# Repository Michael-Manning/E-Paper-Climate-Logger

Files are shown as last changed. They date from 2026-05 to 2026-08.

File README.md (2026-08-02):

# Weathergotchi - an E-Paper Climate Logger

## About

This project is an open-source, battery-powered temperature and humidity data logger with an always-on e-paper display. It records ambient conditions over time, stores readings in non-volatile memory, and displays current data along with a history graph. The device is designed for low power consumption, over 2 weeks of operation on a small Li‑Po battery.

Key features:

- ESP32-S3 with deep sleep & RTC timer to wake up
- Temperature and humidity sensor with external EEPROM for logging
- Accurate battery monitoring and charging management
- Power button controller to turn on/off
- 1.54‑inch e‑paper display
- Custom PCB & 3D‑printed case
- Over 2 weeks of battery life on a single charge

The entire project is open source, including hardware schematics, PCB layout, firmware, and enclosure CAD files. A detailed build video is available on YouTube: [E-Paper Climate Logger](https://www.youtube.com/watch?v=I44iGj7gLGA).

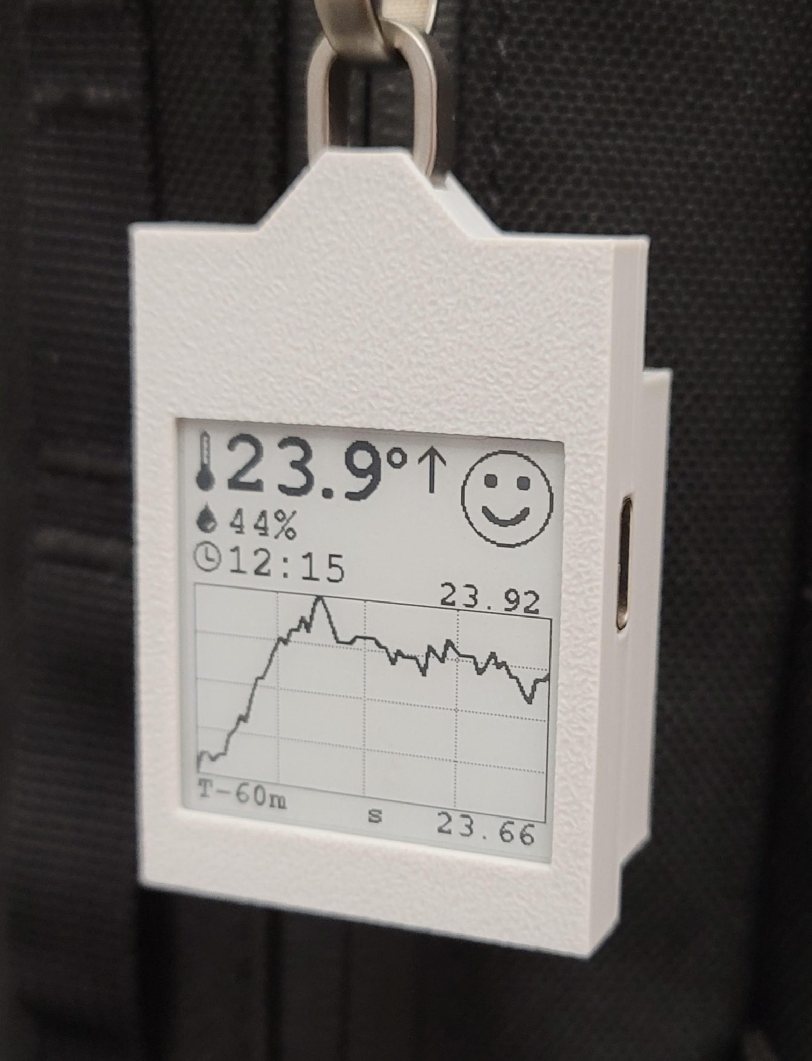
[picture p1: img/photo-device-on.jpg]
photo-device-on

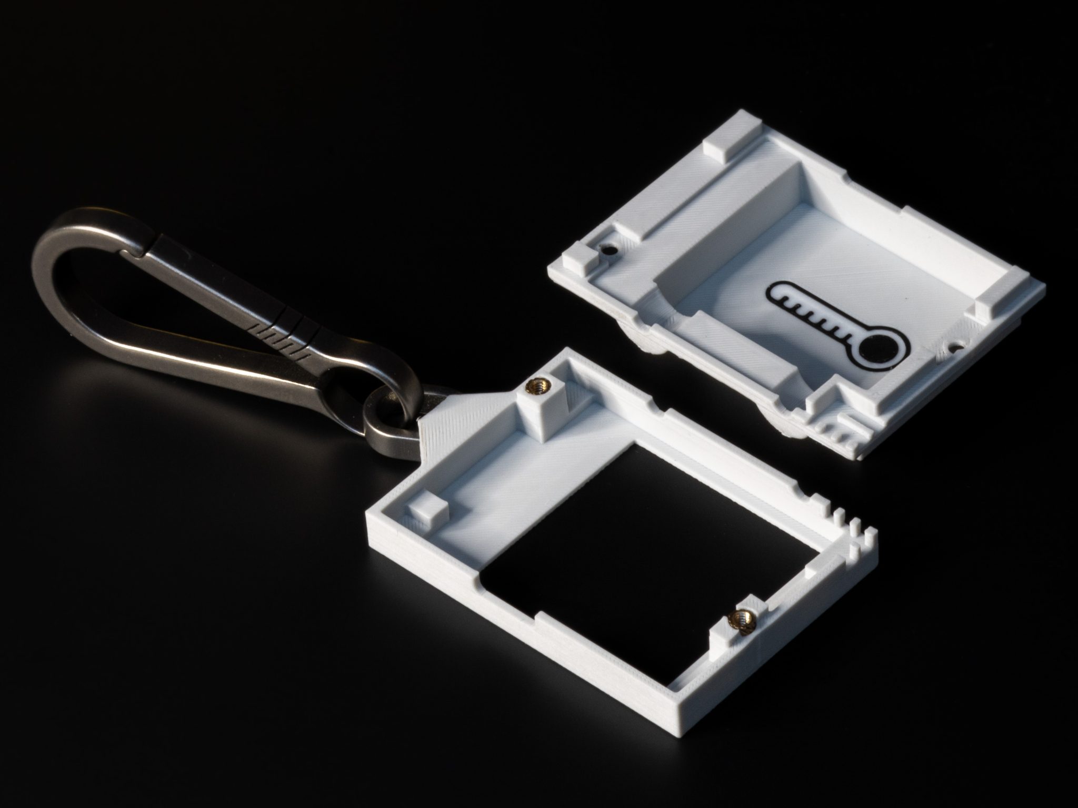
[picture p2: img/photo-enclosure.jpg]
photo-enclosure

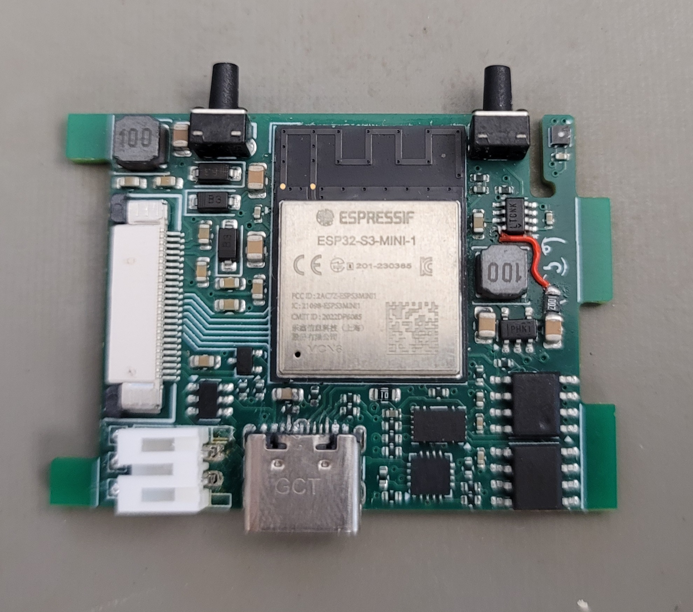
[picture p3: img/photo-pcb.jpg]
photo-pcb


### Youtube video

E-Paper Climate Logger (https://youtu.be/I44iGj7gLGA)

## Repository Structure

```
E-Paper-Climate-Logger/
├── CAD/                 # 3D case design (OpenSCAD source and STL exports)
├── PCB/                 # KiCad hardware design, schematics, datasheets, references
├── firmware/            # PlatformIO firmware (ESP32-S3, Arduino framework)
├── LICENSE              # License file
└── README.md            # This file
```

### CAD

Contains the parametric OpenSCAD models for the front and back case halves, assembly files, and exported STLs for 3D printing. The design is fully parametric – dimensions can be adjusted by editing `constants.scad`.

### PCB

All hardware design files for the custom mainboard (`templog_mainboard`). This directory includes:

- KiCad project files (`.kicad_sch`, `.kicad_pcb`, `.kicad_pro`)
- Schematic sheets for power management and display driver
- Component footprints and 3D models
- Datasheets for all major ICs (charger, fuel gauge, RTC, sensors, etc.)
- Reference schematics from SparkFun and Waveshare

To view or modify the PCB design, install KiCad 9 or later and open `templog_mainboard.kicad_pro`.

### Firmware

PlatformIO project for the ESP32‑S3 using the Arduino framework. It handles sensor reading, timekeeping, data logging to EEPROM, e‑paper display updates, button handling, and power management (deep sleep, wake sources). See `firmware/README.md` for detailed build and flashing instructions.

## Getting Started

### Hardware Prerequisites

- Assembled E-Paper Climate Logger PCB (or a hand‑soldered prototype – note that many components are small and may require reflow soldering)
- 1.54‑inch e‑paper display (compatible with Waveshare pinout)
- 3D‑printed case (files in `CAD/export/`)
- Li‑Po battery (e.g., 400 mAh, single cell)
- USB‑C cable for charging and programming

### Building the Firmware

1. Install [PlatformIO Core](https://platformio.org/install/cli) (or use the PlatformIO extension in VS Code).
2. Navigate to the `firmware` directory.
3. Connect the device via USB‑C.
4. Run:

   ```
   pio run --target upload
   ```

5. Monitor serial output (optional):

   ```
   pio device monitor
   ```

For detailed firmware documentation, including folder structure, driver details, and low‑power operation, refer to [`firmware/README.md`](firmware/README.md).

### Enclosure Assembly

Print the STL files from `CAD/V2/export/` using a high‑resolution FDM printer (0.08 mm layer height recommended). The case uses M2 heat set inserts and M2 screws. Insert the PCB and battery, then screw the front and back halves together. See note.txt in CAD\V2 for more details.

## Hardware Overview

All I2C peripherals (SHT45, DS3231, 24LC512, BQ27441) share the same bus. The e‑paper display is driven via SPI, and the LTC2954 soft power button controls system power-off via the BQ24075.

For complete schematics and PCB layout, open the KiCad project in `PCB/templog_mainboard/`.

## Power Management and Low‑Power Operation

The device is designed to run for over 2 weeks on a small battery:

- In deep sleep, the ESP32‑S3 draws less than 20 µA. The DS3231 and BQ27441 remain active with negligible current.
- The DS3231 alarm wakes the ESP32 at a configurable interval (default: 1 minute). The ESP32 wakes, logs a reading (about 400 ms at 50 mA), updates the display, and returns to sleep.
- The LTC2954 provides a true on/off capability.

## Issues
- **Battery accuracy issues**: In my testing, the reported battery state of charge is not accurate. I believe this is due to a misconfiguration BQ27441.
- **Low battery issues**: In my testing, when connecting a battery to the device, it will sometimes not turn on until the battery has been connected/disconnected multiple times. 

## Notes on building your own device

I don't have a detailed build guide on how to build your own device at this time, but if you do decide to make one, these are some details you should know.

- First firmware upload requires putting the ESP32-S3 in boot mode. There are three pads near the battery input that expose, BOOT, Enable, and ground. Attaching leads to these pins will allow you to put the ESP32 in boot mode.
- The back of the PCB must be completely flat in order to fit in the case with the screen. After soldering through-hole components. like the buttons, you may need a dremel to flatten the leads/solder on the back of the PCB.

## Troubleshooting

- **Device does not power/stay on:** Ensure the battery is charged to at least 3.7V and try disconnecting/reconnecting the battery. Sometimes the battery must be reconnected multiple times before booting for the first time.
- **Battery percentage inaccurate:** The BQ27441 requires a one-time capacity configuration; refer to the datasheet and adjust `BQ27441.cpp`. The fuel gauge also needs to "learn" the battery before it reports an accurate  state of charge. Fully charge the battery, then wait for it to completely deplete. This will help the fuel gauge report a more accurate charge level.
- **Cannot upload program to the device:** Before uploading for the first time, the device must be manually put in boot mode. See the above note in building your own device.

## Limitations
- **Temperature accuracy during handling**: The ESP32 generates heat when active, which can affect the SHT45 reading. The firmware reads the sensor immediately upon wake to minimize this error. Prolonged menu browsing or holding the device will skew the ambient reading for several minutes.
- **Display low‑temperature limit**: The e‑paper module is rated for operation above 0°C. Below freezing, the screen may not update reliably. Data logging continues in the background, and display functionality resumes when the temperature rises.
- **No wireless connectivity**: While this device has the physical capability for bluetooth and WIFI, The current version of the firmware does not support it or allow you to use the radio to export data. Data can be viewed only on the device screen.

## Contributing

Issues, pull requests, and suggestions are welcome. Please follow the existing code style and document any changes to the hardware or firmware.

## License

Refer to the `LICENSE` file in the root directory for licensing terms (open source, permissive).

## Acknowledgements

- SparkFun for the Battery Babysitter reference design
- Waveshare for e‑paper display modules and driver schematics
- The PlatformIO and GxEPD2 communities

For questions or discussions, open an issue on GitHub or visit the YouTube video comments.

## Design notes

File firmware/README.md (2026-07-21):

# Weathergotchi - an E-Paper Climate Logger firmware

## Overview

The firmware runs on an ESP32-S3 microcontroller and is built using PlatformIO with the Arduino framework. It reads temperature and humidity from an SHT45 sensor, stores records in a 24LC512 EEPROM, monitors battery status via a BQ27441 fuel gauge, and displays information on an e-paper screen. The system is designed for low-power operation, entering deep sleep between measurement intervals and waking via the RTC alarm or user buttons.

## Getting Started

### Prerequisites

- PlatformIO Core (installed via pip or standalone installer)
- USB-C cable for programming and power
- Assembled E-Paper Climate Logger hardware

### Dependencies

All required libraries are specified in `platformio.ini` and will be fetched automatically by PlatformIO. The main dependencies include:

- GxEPD2 (e-paper display driver)

The Arduino framework and ESP32-S3 board definition are also handled automatically.

### Building and Flashing

1. Clone the repository and navigate to the firmware directory.
2. Connect the device via USB-C.
3. Build and upload:

   ```
   pio run --target upload
   ```

4. Monitor serial output (optional):

   ```
   pio device monitor
   ```

## Folder Structure

```
firmware/
├── src/
│   ├── drivers/               # Low-level hardware drivers
│   │   ├── BQ27441.cpp/h      # Battery fuel gauge
│   │   ├── BQ27441_Definitions.h
│   │   ├── DS3231.cpp/h       # Real-time clock
│   │   ├── EEPROM.cpp/h       # 24LC512 external EEPROM
│   │   ├── SHT45.cpp/h        # Temperature/humidity sensor
│   │   └── display.cpp/h      # E-paper display (GxEPD2 wrapper)
│   ├── Constants.h            # System-wide constants (sleep intervals, etc.)
│   ├── MAssert.h              # Debug assertions
│   ├── app.cpp/h              # Application state machine and main logic
│   ├── bitmaps.h              # Image data for the display
│   ├── buttons.cpp/h          # Debounced button handling
│   ├── debugLog.h             # Logging macros
│   ├── main.cpp               # Entry point, setup() and loop()
│   ├── pinout.h               # GPIO pin mapping
│   ├── platform.cpp/h         # Hardware abstraction (initialization)
│   ├── power.cpp/h            # Sleep management and wake sources
│   └── timer_setter.h         # Alarm configuration for DS3231
├── extra_script.py            # PlatformIO pre-build script
├── platformio.ini             # Build configuration
└── README.md
```

## General Operation

The firmware executes a simple state machine:

1. **Wake Up Routine**  
   - Climate reading is immediately taken from the SHT45.
   - EEPROM is read to dermine the state of the device.
   - If the device was woken up from the DS3231 alarm:
        - The climate reading is stored to EEPROM.
        - The e-paper display is refreshed with the latest data.
        - The device then returns to deep sleep.

2. **Main Application**  
   - If wake up source was one of the buttons (user interactivity), the device enters the application loop.
   - Different screens and menus can be accessed using the buttons.
   - New settings may be written to EEPROM.
   - Device returns to deep sleep after 10 seconds of innactivity.

3. **Button Handling**  
   - **Power button (GPIO14)** - Wakes device from sleep and opens the main menu.
   - **Menu button (GPIO2)** - Used for navigating the GUI: Debug menu, Settings, Set time
   - **Hold power button 3+ seconds** - Graceful shutdown (LTC2954 cuts power after 6 seconds)

## Operational Notes

### Low-Power Design

- The ESP32-S3 enters deep sleep between logging intervals (default: every 1 minute). 
- Deep sleep current is minimised by disabling unused peripherals.  
- The DS3231 generates a periodic alarm on its INT pin (GPIO21) to wake the MCU.  
- Button wake is enabled via GPIO interrupts.  
- The display is updated only when new data is available or upon user request; no continuous screen refresh occurs.
- The device consumes the majority of its energy during the brief wake period (approximately 3 seconds at 50 mA). Deep sleep current is less than 20 µA (ESP32-S3 + DS3231 + BQ27441). Therefore, reducing the wake interval (e.g., to 5 minutes) will proportionally extend battery life, while a shorter interval (e.g., 30 seconds) will reduce it.
- The DS3231 RTC is configured to generate an alarm **every minute** at second 0. This is hardcoded in `DS3231::SetAlarm1(0)` and cannot be changed without code modification.

### Sleep Behavior

The device implements two sleep levels:
1. **Light sleep** - After 1 second of inactivity. Wakes from buttons, alarm, or 9-second timer.
2. **Deep sleep** - After 10 seconds of inactivity. Wakes only from power button or RTC alarm.

### Logging and Storage

- Data records are stored as binary structs in the 24LC512 EEPROM.  
- The storage implements a circular buffer: when the EEPROM is full, the oldest record is overwritten.  
- A small header area stores the current write index and total record count.  
- Records up to 8 hours ago can be displayed on the e-paper screen on the history menu.
- Upon next power‑on, the firmware reads a flag to determine whether it is resuming from deep sleep or from a complete power‑off. This allows proper initialisation of the real‑time clock, display, and user interface state.

### Temperature Sensor Accuracy

The ESP32‑S3 generates heat during wake‑up and active operation. This heat can conduct through the PCB and affect the SHT45 reading, artificially raising the measured temperature. To mitigate this error, the firmware:

- Reads the sensor immediately upon waking, before any other processing.
- Completes the measurement within the first few milliseconds of wake‑up.

For the most accurate ambient logging, avoid handling the device or placing it in direct sunlight while it is awake.

### Display Low‑Temperature Limit

The e‑paper display module is rated for operation only above 0°C. When the ambient temperature falls below freezing:

- The device continues to log temperature and humidity to EEPROM.
- The screen displays a low temperature warning and stops updating.
- Once the temperature rises above 0°C, normal display operation resumes.
- This is a hardware limitation of the display, not a firmware bug.

### Power Management Hardware

The system includes an LTC2954 soft power button controller and a BQ24075 power path IC. The LTC2954:

- Runs directly from the battery with < 1 µA quiescent current.
- Monitors the physical power button (connected to its `PB_IN`).
- Toggles the enable line of the BQ24075 to completely disconnect or restore battery power.
- Provides a button state output (GPIO14) to the ESP32.
- Accepts a `KILL` input (GPIO37) from the ESP32 to trigger a software shutdown.

## Building Custom Hardware

If you are building a variant of the hardware, update `pinout.h` to match your GPIO assignments. The power management logic (charge status, USB detect, power kill) can be adjusted in `power.cpp` and `platform.cpp`.

---

This README focuses on the firmware as it exists in the repository, using PlatformIO and Arduino. For hardware schematics and PCB design, refer to the `PCB` folder at the root of the project.

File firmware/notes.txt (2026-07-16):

TODO:
- add button sequence to factory reset the EEPROM and fuel gauge
- should re-render display when time range setting is changed, or if new climate data has arrived while the user was in the menu.
- replace datetime version that only has hour/minute/second. Change read/write to only use those registers to save time
- can do some async i2c stuff, like when hibernating, you can hibernate the display at the same time as the eeprom is updated
- create mock EEPROM driver and create unit tests to verify data retrieval logic and ensure there are not bugs related to ring buffer edges.
- update firmware update script to send over the current time before uploading the firmware. That way you get a free clock synchronization every time you upload.
- activate fuel gauge hibernation mode when powering off

Bugs:
- on rare occasion, the display will do a full refresh as the main menu is entered. It should only ever do partial refreshes.
- when the battery first dips below the dead threshold voltage, it can possibly bounce back above the threshold depending on power draw and temperature. This means you can potentially turn it back on few a minutes after the battery dies
    - create some sort of latch in the eerpom so that once the battery dies the device stays in it's dead state until it's actually been connected to a charger for a few minute at least.
- when staying in menus for over a minute, climate samples are stored, but the graph does not show the recent samples until the next natural wake up cycle. Fix: update global sample buffer in addition to calling AddClimateSample()
- connecting the charging cable, then it sometimes causes the device to get stuck on the charging screen until a button is pressed.

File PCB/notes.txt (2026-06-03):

------------- Parts -------------

sensor:
SHT45

controller:
ESP32-S3-MINI-1

eeprom:
24LC512

fuel guage:
BQ27441

charger:
BQ24075

battery:

RTC:
DS3231MZ

USB connector:
GCT USB4105

Power path selector:
LM66200DRLR

USB voltage regulator:
TLV75533PDBVR

connector
FPC-05F-24PH20

------------- I2C Addresses -------------
7 bit representation / 8 bit representation

DS3231MZ:
0x68 / 0xD0

SHT45-A (letter determines address)
0x44

BQ27441
0x55

24LC512 (last three bits are determined by A0, A1, A3 pins. Set all to ground for 000)
0x50

------------ References --------------

Battery management reference:
https://cdn.sparkfun.com/assets/learn_tutorials/5/3/0/sparkfun-battery-babysitter-v10-schematic.pdf

esp32 raw e-ink driver example PCB:
https://www.waveshare.com/wiki/E-Paper_ESP32_Driver_Board

pinouts:
https://github.com/atomic14/esp32-s3-pinouts

https://www.waveshare.com/wiki/1.54inch_e-Paper_Module_Manual#Resources

------------ Problems ----------------

Charging rate is very slow. The BQ2407 resister configuration is set to the slowest charging rate which takes over an hour.

fuel gauge GPOUT has a battery level pullup. This required a trace cut because it should be pulled up to 3.3V. Add back in with a voltage divider.

CHG status is not connected to an RTC pin, so the device can't be automatically woken up by USB connection.
USBdetect pin cannot be used instead because it does not pull low.

board capacitance takes over 10 seconds to bring 3.3v rail to 0v. This causes the display to artifact when powering down. 
Might need a mosfet to completely power down the display, or some way to discharge the leftover power

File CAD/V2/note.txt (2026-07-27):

I wanted the case to have rounded corners, so I made this version in FreeCAD.

The model works well, but the parameters are a mess. I just copied over all the variables from the OpenSCAD model and didn't even use half of them.

The other big change is that this version uses 5mm M2 screws without a heat insert. It just has self tap holes to make assembly easier.
It also has a small retention clip on the corner furthest from a screw to help keep it flat.

Notes for putting it together with this case:
- don't use/desolder the battery connector. This case only fits if you solder the battery directly to the PCB.
- Tuck the excess battery wire into the side of the battery compartment.
- Print with a 0.2mm nozzle and 0.08mm layer height.
- Print in PLA and use PETG for the support interface layer on the back for smoother finish.
- Sand the edges and corners of the PCB if the fit is too tight.
- Do not force anything. It should come together easily and the case will bend if you force it together.
- The case is designed to be connected to an titanium clip commonly found on Aliexpress (see clip.png). When slicing the front of the case, insert a pause on the last layer before the clip insertion slot is closed up. Remove the small loop of the clip and place it into the slot before resuming the print so that it stays captive inside the case. I  reccomend adding a 0.8mm tall platform near the top of the case as well so that the loop lays perfectly flat when being printed over.

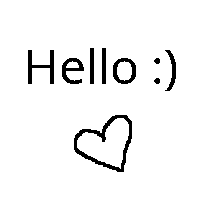
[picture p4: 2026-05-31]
firmware/bitmapGenerator/images/welcom_screen.bmp

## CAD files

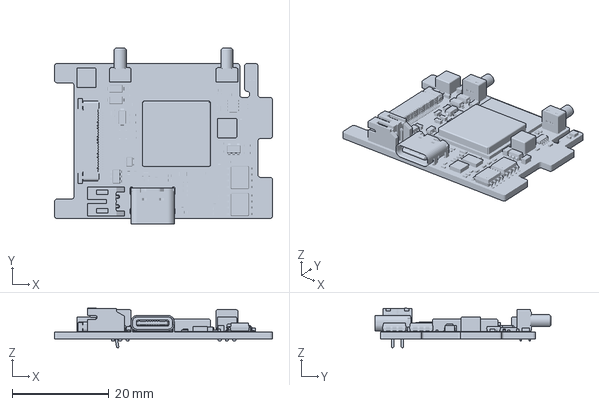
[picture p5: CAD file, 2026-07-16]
CAD/V2/mainboard.FCStd
45.0 x 36.3 x 8.25 mm

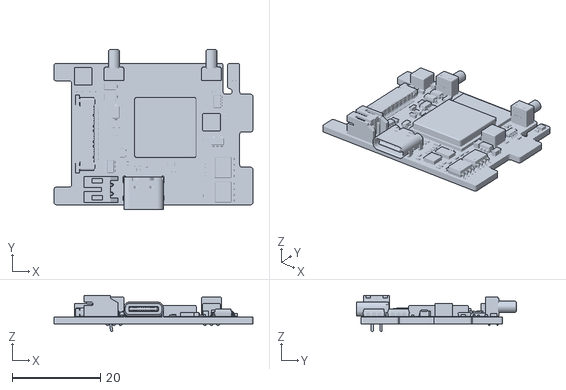
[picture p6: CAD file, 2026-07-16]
CAD/V2/templog_mainboard.stl
45.0 x 36.3 x 8.25

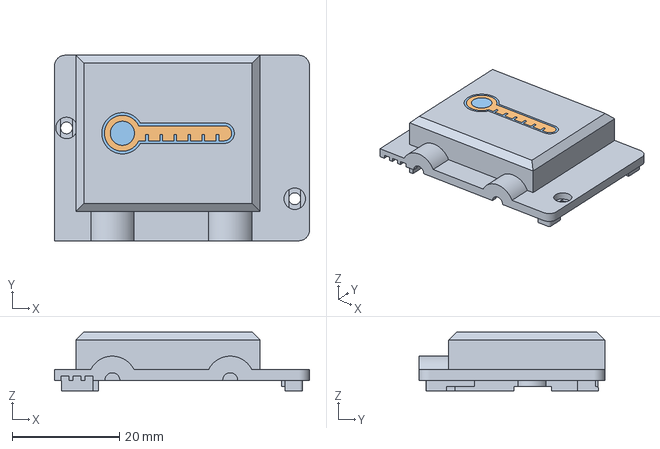
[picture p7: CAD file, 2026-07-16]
CAD/V2/export/case_back_multi_color.3mf
47.6 x 34.6 x 11.0 mm

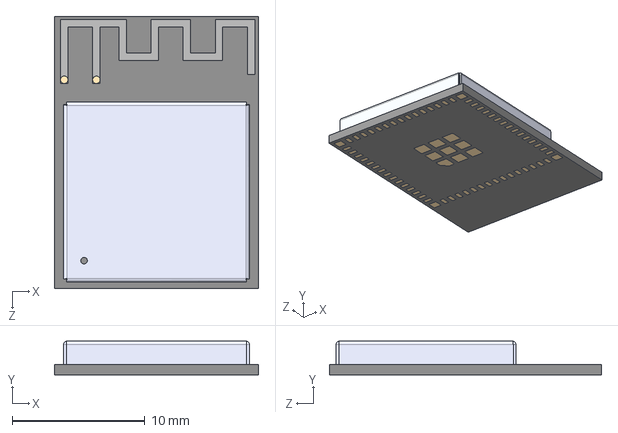
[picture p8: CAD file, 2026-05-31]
PCB/templog_mainboard/PartLibrary/ESP32_S3_MINI_1/3DModel/ESP32-S3-MINI-1.STEP
15.4 x 2.55 x 20.5 mm

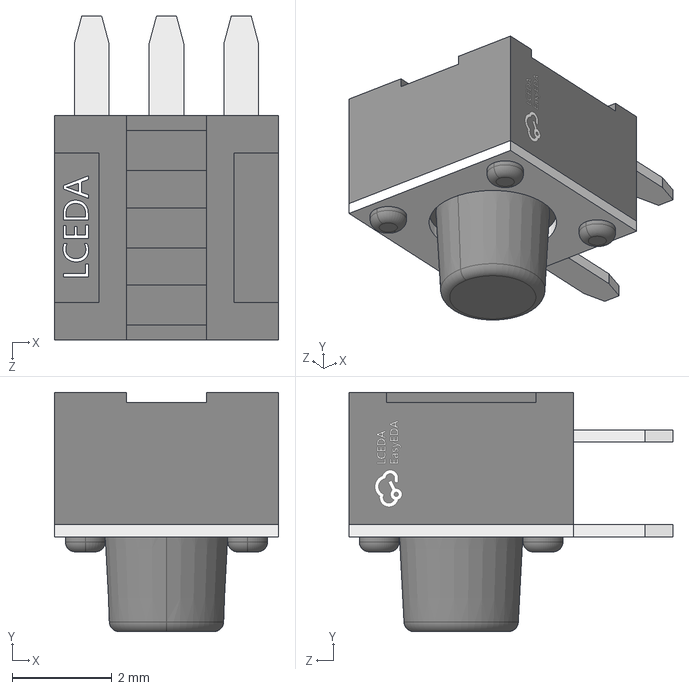
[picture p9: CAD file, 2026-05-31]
PCB/templog_mainboard/PartLibrary/K2-1109DE-D4SW-01/3DModel/KEY-TH_K2-L4.5-W2.9-H4.5-P3.0.step
4.50 x 4.80 x 6.50 mm

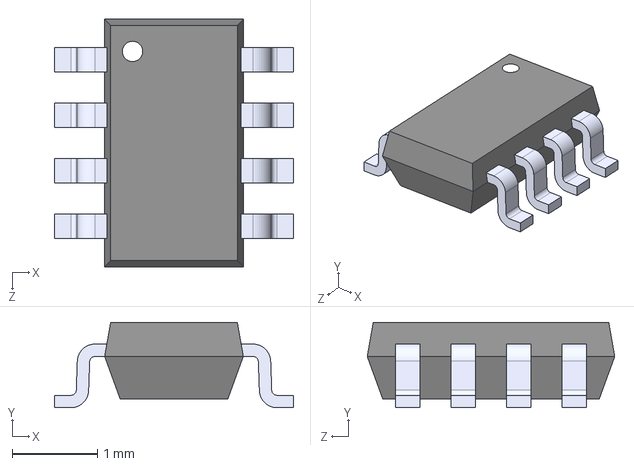
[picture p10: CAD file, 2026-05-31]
PCB/templog_mainboard/PartLibrary/LTC2954CTS8_2_TRMPBF/3DModel/LTC2954CTS8-2_TRMPBF.step
2.80 x 1.00 x 2.90 mm

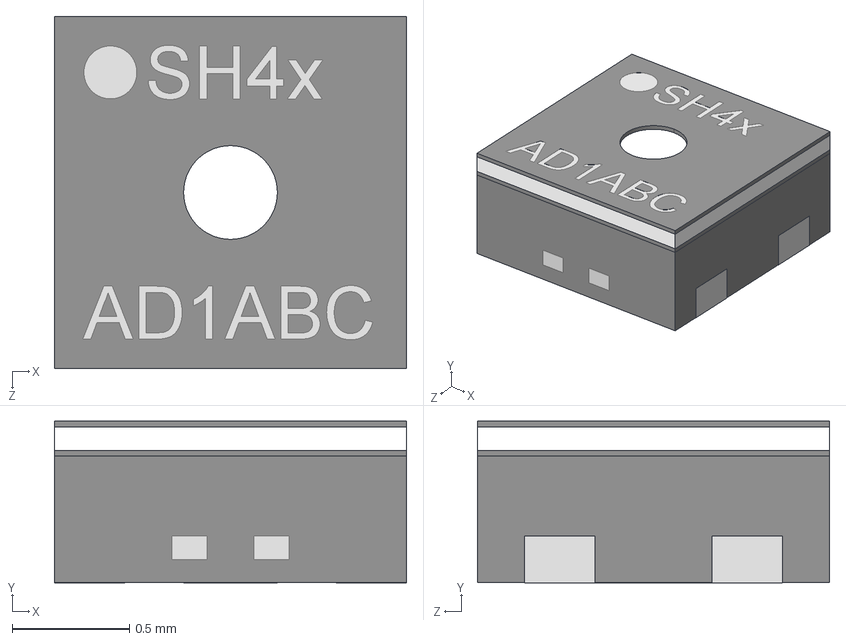
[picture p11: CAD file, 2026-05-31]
PCB/templog_mainboard/PartLibrary/SHT45/3DModel/SHT45-AD1B-R3.step
1.50 x 0.691 x 1.50 mm

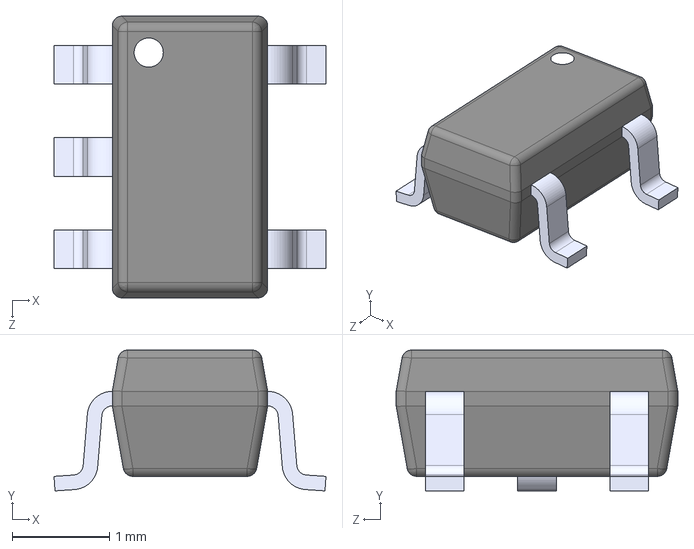
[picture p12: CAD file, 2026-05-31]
PCB/templog_mainboard/PartLibrary/SN74LVC1G79DBVR/3DModel/SN74LVC1G79DBVR.step
2.80 x 1.45 x 2.90 mm

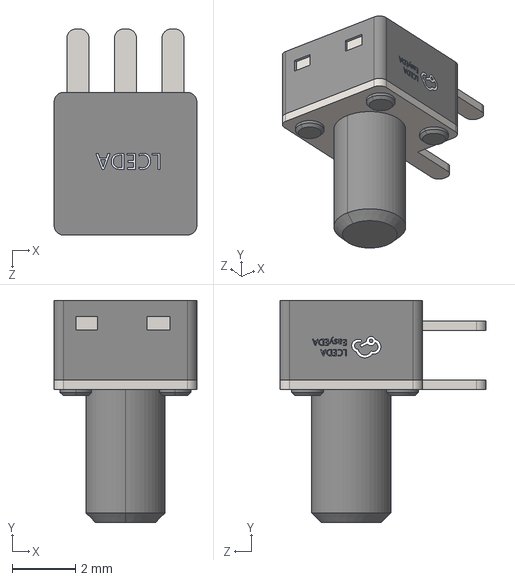
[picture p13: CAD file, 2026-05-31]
PCB/templog_mainboard/PartLibrary/TC-1109DE-C-H/3DModel/SW-TH_TC-1109DE-C-H.step
4.50 x 7.00 x 6.50 mm

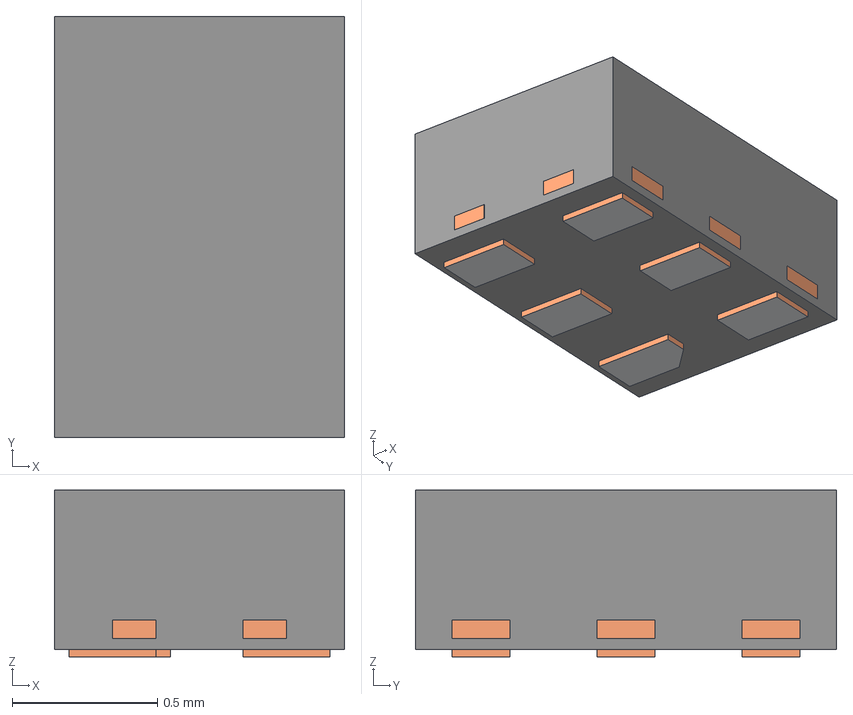
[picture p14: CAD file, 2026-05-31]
PCB/templog_mainboard/PartLibrary/TPS3422EGDRYR/3DModel/DRY0006A.stp
1.00 x 1.45 x 0.575 mm
BODY-SON
FRAME-DRY0006A
PIN1-ID

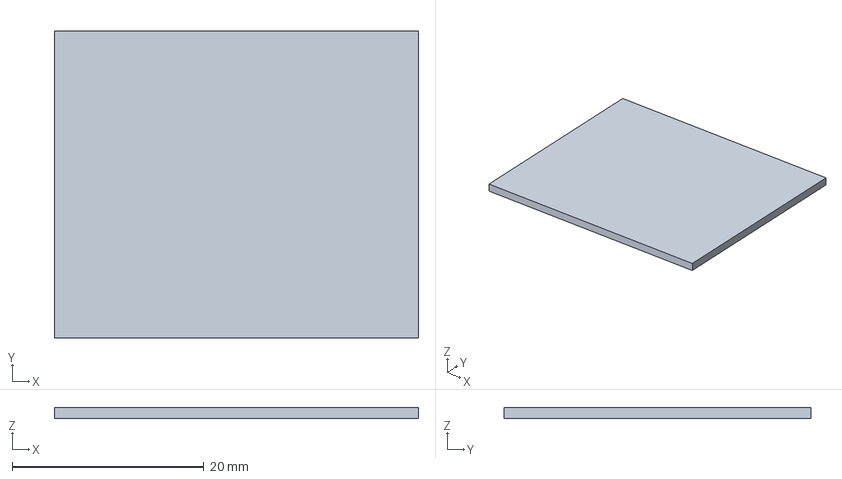
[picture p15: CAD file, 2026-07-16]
CAD/V2/screen.FCStd
38.0 x 32.0 x 1.20 mm

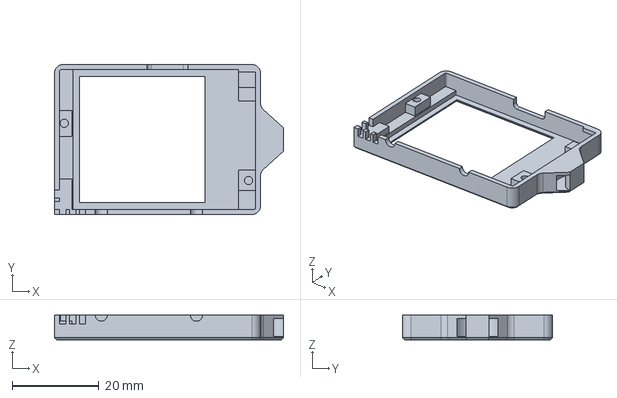
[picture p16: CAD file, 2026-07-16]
CAD/V2/case_front.FCStd
52.9 x 34.6 x 5.70 mm

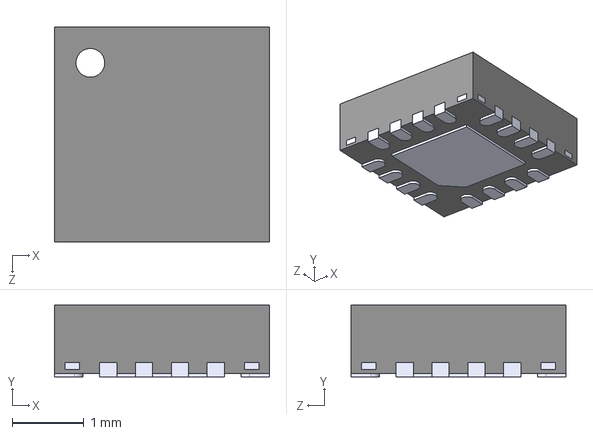
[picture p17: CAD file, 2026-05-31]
PCB/templog_mainboard/PartLibrary/BQ24075RGT/3DModel/BQ24075RGTR.step
3.00 x 1.00 x 3.00 mm

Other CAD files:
CAD/V2/assembly.FCStd
CAD/V2/case_back.FCStd
CAD/V2/variables.FCStd
CAD/V2/comparison.FCStd
CAD/V1/constants.scad
CAD/V1/assembly.scad
CAD/V1/case_back.scad
CAD/V1/case_front.scad
CAD/V1/export/case_back_P1.stl
CAD/V1/export/case_back_P2.stl
CAD/V1/export/case_back_P3.stl
CAD/V1/export/case_front.stl
CAD/V2/export/case_back.3mf
CAD/V2/export/case_front.3mf

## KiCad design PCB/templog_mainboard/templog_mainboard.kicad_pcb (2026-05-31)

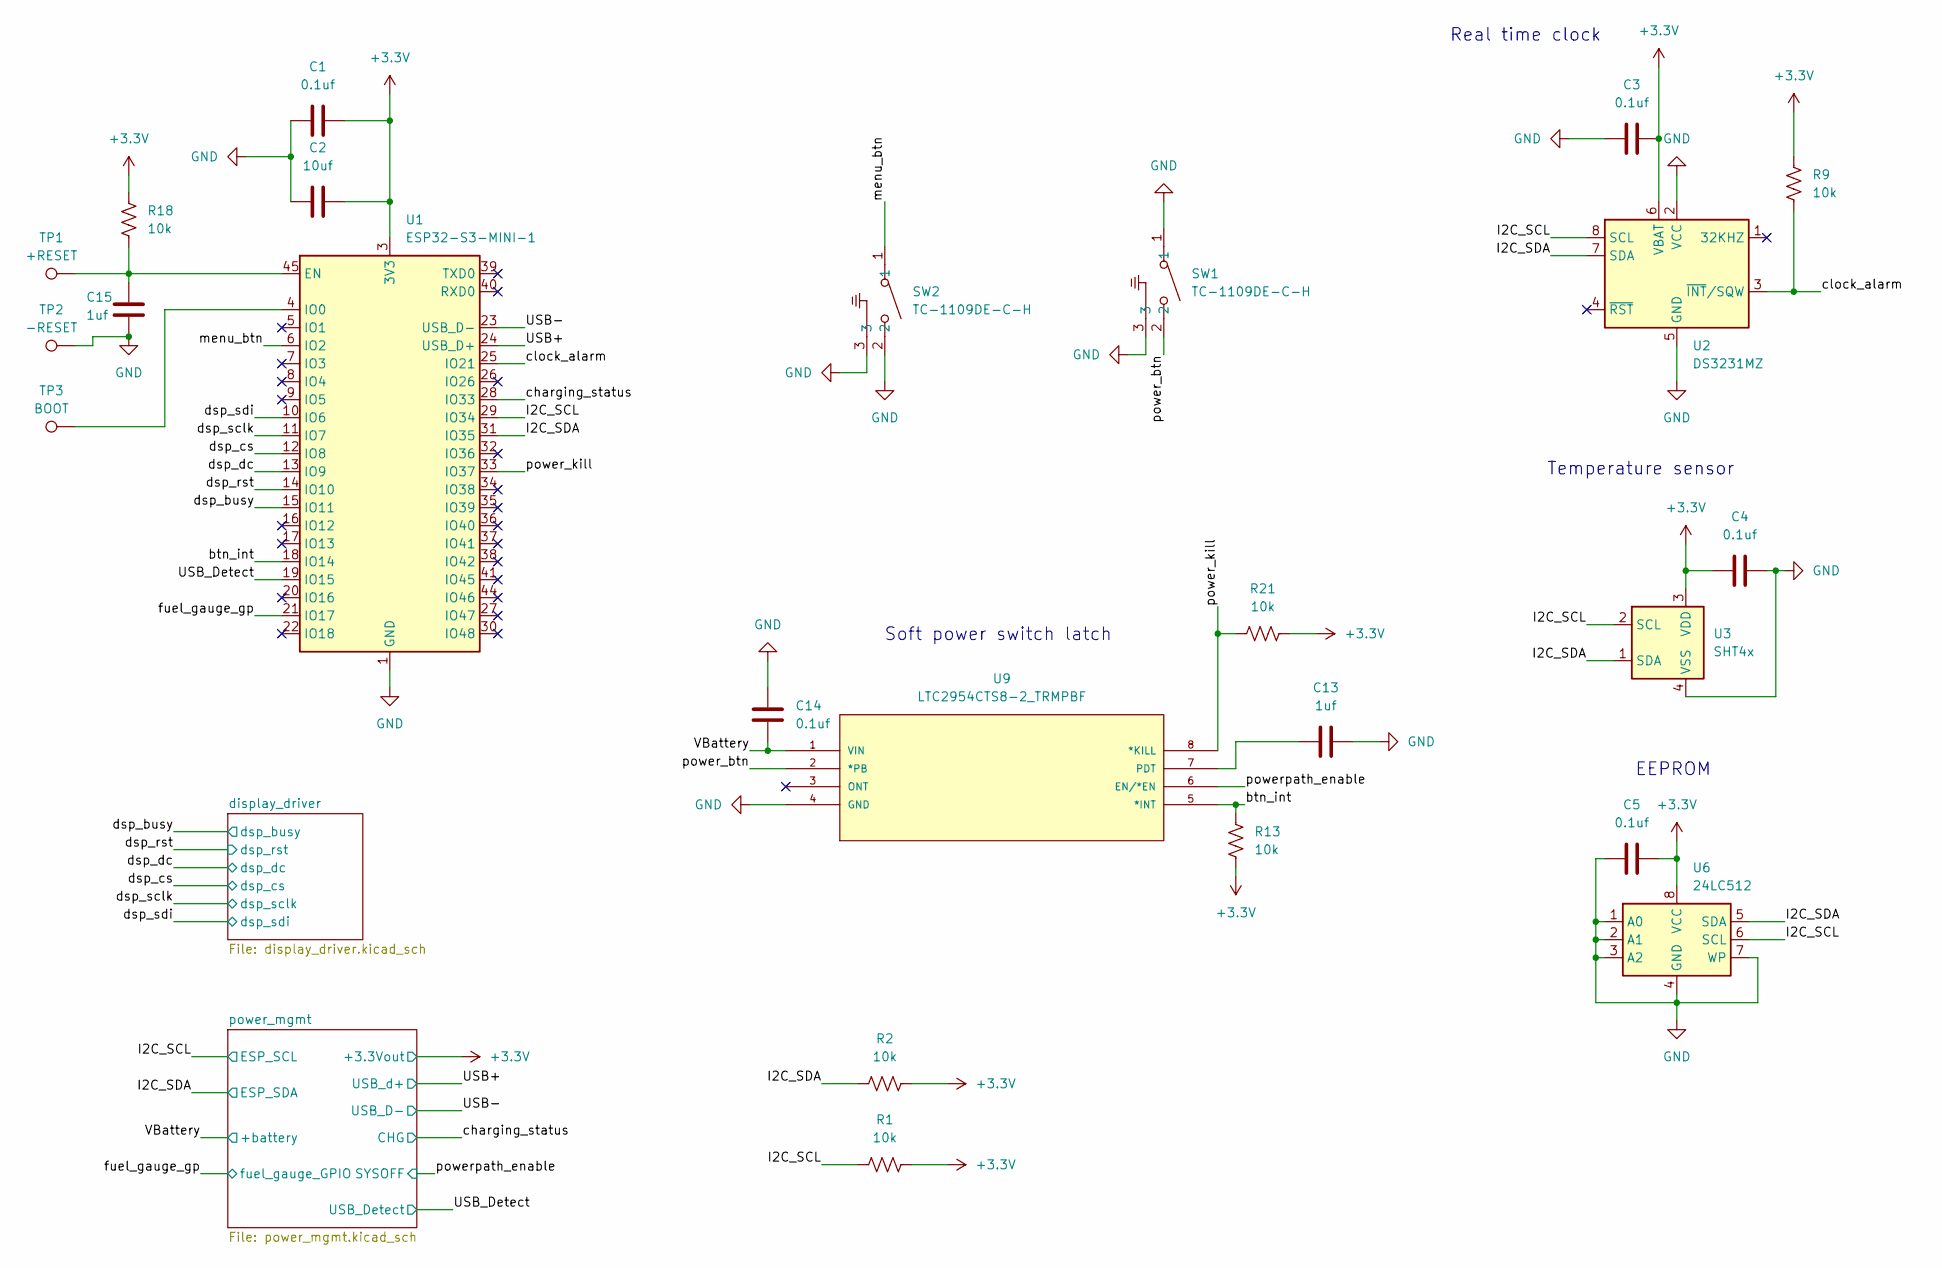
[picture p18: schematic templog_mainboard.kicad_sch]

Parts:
C1, C3, C4, C5, C14: 0.1uf; C_0402_1005Metric
C2: 10uf; C_0805_2012Metric
C13: 1uf; C_0603_1608Metric
C15: 1uf; C_0402_1005Metric
R1, R2, R9, R13, R18, R21: 10k; R_0402_1005Metric
SW1, SW2: TC-1109DE-C-H; SW-TH_TC-1109DE-C-H; LCSC Part C400335
TP1: +RESET; TestPoint_Pad_1.0x1.0mm
TP2: -RESET; TestPoint_Pad_1.0x1.0mm
TP3: BOOT; TestPoint_Pad_1.0x1.0mm
U1: ESP32-S3-MINI-1; ESP32-S2-MINI-1; LCSC Part # C2913206
U2: DS3231MZ; SOIC-8_3.9x4.9mm_P1.27mm; LCSC Part # C107410
U3: SHT4x; Sensirion_DFN-4_1.5x1.5mm_P0.8mm_SHT4x_NoCentralPad; LCSC Part # C5360602
U6: 24LC512; SOIC-8_3.9x4.9mm_P1.27mm; LCSC Part # C52088
U9: LTC2954CTS8-2_TRMPBF; TSOT-23_TS8; MANUFACTURER_PART_NUMBER ltc2954cts81; LCSC Part # C580656

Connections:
+3.3V: C1.2, C2.2, C3.2, C4.1, C5.2, R1.2, R2.2, R9.1, R13.2, R18.1, R21.1, U1.3 (3V3), U2.6 (VBAT), U3.3 (VDD), U6.8 (VCC); also elsewhere on the board
/I2C_SCL: R1.1, U1.29 (IO34), U2.8 (SCL), U3.2 (SCL), U6.6 (SCL); also elsewhere on the board
/I2C_SDA: R2.1, U1.31 (IO35), U2.7 (SDA), U3.1 (SDA), U6.5 (SDA); also elsewhere on the board
/USB+: U1.24 (USB_D+); also elsewhere on the board
/USB-: U1.23 (USB_D-); also elsewhere on the board
/USB_Detect: U1.19 (IO15); also elsewhere on the board
/VBattery: C14.1, U9.1 (VIN); also elsewhere on the board
/btn_int: R13.1, U1.18 (IO14), U9.5 (*INT)
/charging_status: U1.28 (IO33); also elsewhere on the board
/clock_alarm: R9.2, U1.25 (IO21), U2.3 (~INT/SQW)
/dsp_busy: U1.15 (IO11); also elsewhere on the board
/dsp_cs: U1.12 (IO8); also elsewhere on the board
/dsp_dc: U1.13 (IO9); also elsewhere on the board
/dsp_rst: U1.14 (IO10); also elsewhere on the board
/dsp_sclk: U1.11 (IO7); also elsewhere on the board
/dsp_sdi: U1.10 (IO6); also elsewhere on the board
/fuel_gauge_gp: U1.21 (IO17); also elsewhere on the board
/menu_btn: SW2.1, U1.6 (IO2)
/power_btn: SW1.2, U9.2 (*PB)
/power_kill: R21.2, U1.33 (IO37), U9.8 (*KILL)
/powerpath_enable: U9.6 (EN/*EN); also elsewhere on the board
GND: C1.1, C2.1, C3.1, C4.2, C5.1, C13.2, C14.2, C15.2, SW1.1, SW1.3, SW2.2, SW2.3, TP2.1, U1.1 (GND), U1.2 (GND), U1.42 (GND), U1.43 (GND), U1.46 (GND), U1.47 (GND), U1.48 (GND), U1.49 (GND), U1.50 (GND), U1.51 (GND), U1.52 (GND), U1.53 (GND), U1.54 (GND), U1.55 (GND), U1.56 (GND), U1.57 (GND), U1.58 (GND), U1.59 (GND), U1.60 (GND), U1.61 (GND), U1.62 (GND), U1.63 (GND), U1.64 (GND), U1.65 (GND), U2.2 (VCC), U2.5 (GND), U3.4 (VSS), U6.1 (A0), U6.2 (A1), U6.3 (A2), U6.4 (GND), U6.7 (WP), U9.4 (GND); also elsewhere on the board
unnamed: C15.1, R18.2, TP1.1, U1.45 (EN)
unnamed: TP3.1, U1.4 (IO0)
unnamed: C13.1, U9.7 (PDT)

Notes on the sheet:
Soft power switch latch
Real time clock
Temperature sensor
EEPROM

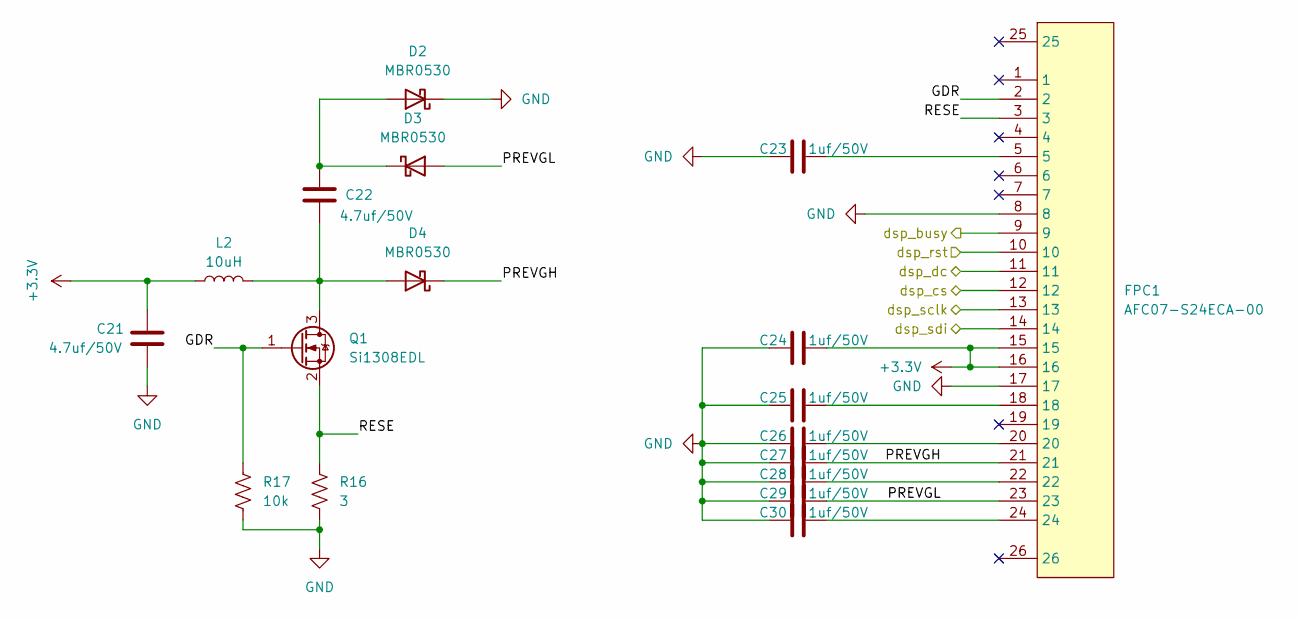
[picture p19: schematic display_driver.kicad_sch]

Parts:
C21, C22: 4.7uf/50V; C_0805_2012Metric
C23, C24, C25, C26, C27, C28, C29, C30: 1uf/50V; C_0603_1608Metric
D2, D3: MBR0530; D_SOD-123
D4: MBR0530; D_SOD-123; LCSC Part # C77336
FPC1: AFC07-S24ECA-00; FPC-SMD_AFC07-S24ECA-00; LCSC Part # C262643
L2: 10uH; L_Sunlord_SWPA4030S; LCSC Part # C38117
Q1: Si1308EDL; SOT-323_SC-70; LCSC Part # C469327
R16: 3; R_0402_1005Metric
R17: 10k; R_0402_1005Metric

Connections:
+3.3V: C21.1, C24.2, FPC1.15, FPC1.16, L2.1; also elsewhere on the board
/display_driver/GDR: FPC1.2, Q1.1 (G), R17.2
/display_driver/PREVGH: C27.2, D4.1 (K), FPC1.21
/display_driver/PREVGL: C29.2, D3.2 (A), FPC1.23
/display_driver/RESE: FPC1.3, Q1.2 (S), R16.2
/dsp_busy: FPC1.9; also elsewhere on the board
/dsp_cs: FPC1.12; also elsewhere on the board
/dsp_dc: FPC1.11; also elsewhere on the board
/dsp_rst: FPC1.10; also elsewhere on the board
/dsp_sclk: FPC1.13; also elsewhere on the board
/dsp_sdi: FPC1.14; also elsewhere on the board
GND: C21.2, C23.1, C24.1, C25.1, C26.1, C27.1, C28.1, C29.1, C30.1, D2.1 (K), FPC1.8, FPC1.17, R16.1, R17.1; also elsewhere on the board
unnamed: C23.2, FPC1.5
unnamed: C25.2, FPC1.18
unnamed: C26.2, FPC1.20
unnamed: C28.2, FPC1.22
unnamed: C30.2, FPC1.24
unnamed: C22.1, D2.2 (A), D3.1 (K)
unnamed: C22.2, D4.2 (A), L2.2, Q1.3 (D)

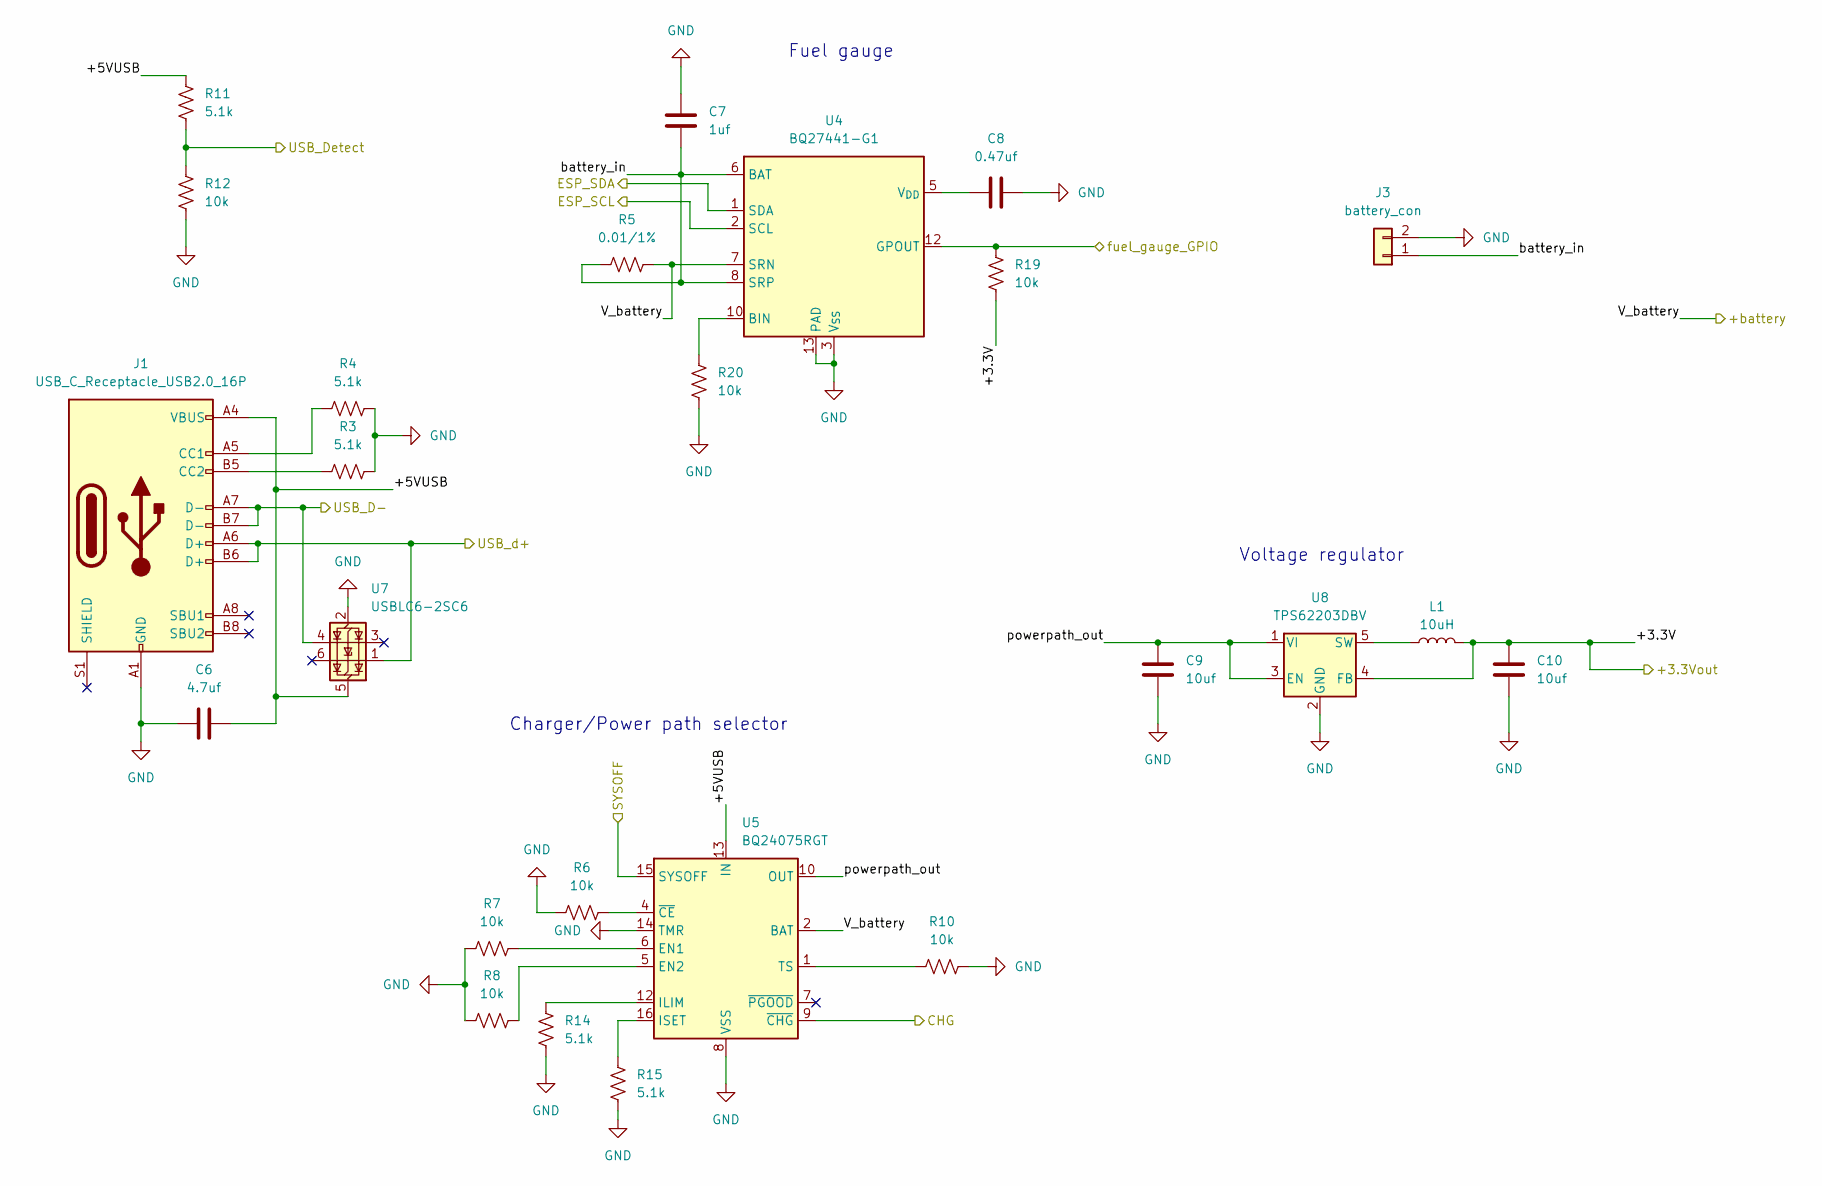
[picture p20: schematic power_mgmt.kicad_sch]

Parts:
C6: 4.7uf; C_0603_1608Metric
C7: 1uf; C_0402_1005Metric
C8: 0.47uf; C_0402_1005Metric
C9, C10: 10uf; C_0805_2012Metric
J1: USB_C_Receptacle_USB2.0_16P; USB_C_Receptacle_GCT_USB4105-xx-A_16P_TopMnt_Horizontal
J3: battery_con; JST_PH_S2B-PH-K_1x02_P2.00mm_Horizontal
L1: 10uH; L_Sunlord_SWPA4030S; LCSC Part # C38117
R3, R4, R11, R14, R15: 5.1k; R_0402_1005Metric
R5: 0.01/1%; R_0603_1608Metric
R6, R7, R8, R10, R12, R19, R20: 10k; R_0402_1005Metric
U4: BQ27441-G1; Texas_S-PDSO-N12; LCSC Part # C473374
U5: BQ24075RGT; VQFN-16-1EP_3x3mm_P0.5mm_EP1.6x1.6mm; LCSC Part # C15464
U7: USBLC6-2SC6; SOT-23-6; LCSC Part # C7519
U8: TPS62203DBV; SOT-23-5; LCSC Part # C9051

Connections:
+3.3V: C10.2, L1.2, R19.1, U8.4 (FB); also elsewhere on the board
/I2C_SCL: U4.2 (SCL); also elsewhere on the board
/I2C_SDA: U4.1 (SDA); also elsewhere on the board
/USB+: J1.A6 (D+), J1.B6 (D+), U7.1 (I/O1); also elsewhere on the board
/USB-: J1.A7 (D-), J1.B7 (D-), U7.4 (I/O2); also elsewhere on the board
/USB_Detect: R11.1, R12.2; also elsewhere on the board
/VBattery: R5.2, U4.7 (SRN), U5.2 (BAT), U5.3 (BAT); also elsewhere on the board
/charging_status: U5.9 (~CHG); also elsewhere on the board
/fuel_gauge_gp: R19.2, U4.12 (GPOUT); also elsewhere on the board
/power_mgmt/+5VUSB: C6.1, J1.A4 (VBUS), J1.A9 (VBUS), J1.B4 (VBUS), J1.B9 (VBUS), R11.2, U5.13 (IN), U7.5 (VBUS)
/power_mgmt/battery_in: C7.2, J3.1, R5.1, U4.6 (BAT), U4.8 (SRP)
/power_mgmt/powerpath_out: C9.2, U5.10 (OUT), U5.11 (OUT), U8.1 (VI), U8.3 (EN)
/powerpath_enable: U5.15 (SYSOFF); also elsewhere on the board
GND: C6.2, C7.1, C8.1, C9.1, C10.1, J1.A1 (GND), J1.A12 (GND), J1.B1 (GND), J1.B12 (GND), J3.2, R3.2, R4.2, R6.1, R7.1, R8.1, R10.2, R12.1, R14.1, R15.1, R20.2, U4.3 (V_{SS}), U4.13 (PAD), U5.8 (VSS), U5.14 (TMR), U5.17 (VSS), U7.2 (GND), U8.2 (GND); also elsewhere on the board
unnamed: J1.A5 (CC1), R4.1
unnamed: J1.B5 (CC2), R3.1
unnamed: R20.1, U4.10 (BIN)
unnamed: C8.2, U4.5 (V_{DD})
unnamed: R7.2, U5.6 (EN1)
unnamed: R8.2, U5.5 (EN2)
unnamed: R14.2, U5.12 (ILIM)
unnamed: R15.2, U5.16 (ISET)
unnamed: R10.1, U5.1 (TS)
unnamed: R6.2, U5.4 (~CE)
unnamed: L1.1, U8.5 (SW)

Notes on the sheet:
Voltage regulator
Charger/Power path selector
Fuel gauge

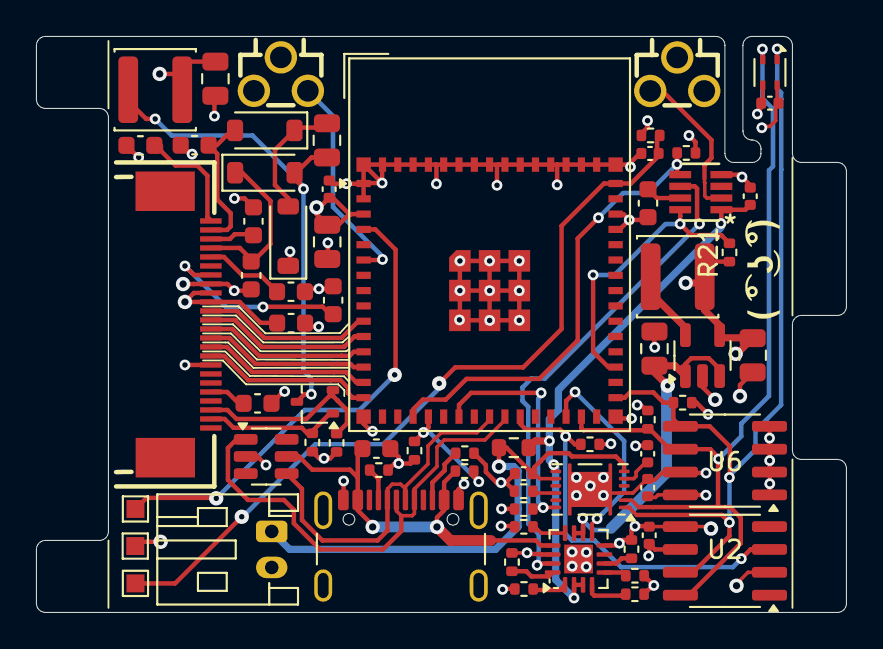
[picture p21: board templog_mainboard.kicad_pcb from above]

Board: 4 copper layers, 45.0 x 32.0 mm, 67 parts (0 on the bottom side), 50 nets.

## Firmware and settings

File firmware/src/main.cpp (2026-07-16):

#include <Arduino.h>
#include <SPI.h>
#include <Wire.h>
#include <driver/adc.h>
#include <stdint.h>

#include "MAssert.h"
#include "app.h"
#include "buttons.h"
#include "debugLog.h"
#include "drivers/DS3231.h"
#include "drivers/EEPROM.h"
#include "drivers/SHT45.h"
#include "drivers/display.h"
#include "pinout.h"
#include "platform.h"
#include "power.h"
// #include "timer_setter.h"
#include "Constants.h"
#include "bitmaps.h"

#include "esp_sleep.h"
#include <esp_timer.h>
#include "driver/rtc_io.h"
#include <Fonts/FreeMonoBold12pt7b.h>


bool debugLogUSBConnected = false;

unsigned long time_start_ms;
unsigned long time_now_s;
#define COLORED 0
#define UNCOLORED 1

constexpr uint32_t _lightSleepInactivityThreshold_ms = 1000;         // 1s
constexpr uint32_t _deepSleepInactivityThreshold_ms = 10000;         // 10s
constexpr uint32_t _extendedDeepSleepInactivityThreshold_ms = 30000; // 30s

using namespace plt;

namespace {
    
EEPROM eeprom;
DS3231 _clock;
Display _display;
App app;

GlobalState globalState = {};

uint32_t lightSleepInactivityTimer_ms = 0;
uint32_t deepSleepInactivityTimer_ms = 0;
uint32_t programStartTimer_ms = 0;
uint32_t clockReadTimer_ms = 0;

// Indicates the last wake up was specifically caused by pressing the power button while the night screen was shown.
// This is needed to prevent the menu from being shown before the standard display.
bool manualWakeUpFromNightScreen = false;


constexpr uint32_t GetLightSleepInactivityThreshold_ms()
{
    return _lightSleepInactivityThreshold_ms;
}
uint32_t GetDeepSleepInactivityThreshold_ms()
{
    // When the view data screen is open, use a longer timeout.
    if(app.getState() == State::ViewData || app.getState() == State::EReader)
        return _extendedDeepSleepInactivityThreshold_ms;
    return _deepSleepInactivityThreshold_ms;
}


}  // namespace


void on_error(const char* cond, const char* file, int line) {
   Serial.printf("ERROR: assertion failed (%s) -- %s line: %d\n", cond, file, line);
}

void resetInactivity(){
    uint64_t now = millis(); 
    deepSleepInactivityTimer_ms  = now;
    lightSleepInactivityTimer_ms = now;
}

void configurePins() {
   setPinMode(pins::menuBtn, PinMode::Input_Pullup);
   setPinMode(pins::powerBtn, PinMode::Input);
   setPinMode(pins::powerKill, PinMode::Input);
   setPinMode(pins::USBDetect, PinMode::Input);
   setPinMode(pins::fuelGaugeGPIO, PinMode::Input);
   setPinMode(pins::chargeStatus, PinMode::Input_Pullup);
   setPinMode(pins::clockAlarm, PinMode::Input);
}

void configureRTC() {
   DS3231::Control c;
   c.bits.disableOscillator = 0;
   c.bits.squareWaveEnable = 0;
   c.bits.convertTemperature = 0;
   c.bits.interruptControl = 1;
   c.bits.alarm2InterruptEnable = 0;
   c.bits.alarm1InterruptEnable = 1;
   _clock.SetControl(c);

   _clock.SetAlarm1(0);
}

void loadClimateDate(){
    int loadRange = 60;

    switch (globalState.currentSettings.graphRange)
    {
    case GraphRange::_10Minutes :
        loadRange = 10;
        break;
    case GraphRange::_20Minutes :
        loadRange = 20;
        break;
    case GraphRange::_30Minutes :
        loadRange = 30;
        break;
    case GraphRange::_60Minutes :
        loadRange = 60;
        break;
    default:
        break;
    }

    uint16_t requestAmount = globalState.currentHeader.dataCount < loadRange ? globalState.currentHeader.dataCount : loadRange; 

    uint16_t actualCount;
    eeprom.GetClimateSamples(
        globalState.currentHeader, 
        globalState.climateHistory.data(),  
        requestAmount,
        0,
        actualCount
    );
    globalState.historyEnd = 0;
    globalState.historyStart = actualCount;
}

void handleDeadBattery(bool displayCold, bool shouldFullResetDisplay){
    globalState.currentHeader.shutDownReason = ShutDownReason::LowBattery;
                
    // if the device dies while it's already cold, there's nothing we can do. Just shut down.
    // Don't bother refreshing the screen if EEPROM indicates it's already being shown.
    if(displayCold == false && globalState.currentHeader.displayingLowBattery == false)
    {  
        _display.Init(shouldFullResetDisplay, &globalState.currentHeader);
        
        _display.ForceFullNextRefresh();
        _display.StartRefresh();
        _display.d->setRotation(2);
        _display.d->fillScreen(GxEPD_WHITE);
        _display.d->drawBitmap(0, 0, bitmaps::dead_battery_screen, 200, 200, GxEPD_BLACK);
        _display.EndRefresh();

        globalState.currentHeader.displayingLowBattery = true;
        globalState.currentHeader.displayingCold = false;
        globalState.currentHeader.displayingNightMode = false;

        eeprom.StartNextStatusHeader(globalState.currentHeader);
        eeprom.UpdateStatusHeader(globalState.currentHeader);
        
        delay(50);
    }
    

    _display.ShutDown();
    power::ShutdownSystem();
}

void preHibernateTasks(){
    
    if(globalState.currentHeader.displayingCold)
        _display.ShutDown();
    else
        _display.Hibernate();
    
    // write to eeprom
    logl("updating header");
    if(power::USBConnected() && globalState.currentHeader.shutDownReason == ShutDownReason::FirmwareUpdate)
    {
        // probably never happens
        globalState.currentHeader.shutDownReason = ShutDownReason::FirmwareUpdate;
    }
    else{
        globalState.currentHeader.shutDownReason = ShutDownReason::Hibernate;
    }
    
    eeprom.UpdateStatusHeader(globalState.currentHeader);

    if(debugLogUSBConnected){
        logl("going back to sleep...");
        delay(200);
    }
}

static bool isNightHours(const DateTime& t){
    // nightModeHourStart > nightModeHourEnd means the range wraps midnight (e.g. 23:00 - 06:00)
    if(Constants::nightModeHourStart > Constants::nightModeHourEnd)
        return t.Hour >= Constants::nightModeHourStart || t.Hour < Constants::nightModeHourEnd;
    else
        return t.Hour >= Constants::nightModeHourStart && t.Hour < Constants::nightModeHourEnd;
}

// when woken up by alarm, just quickly update then screen then go back to sleep;
void doAlarmRoutine(bool updateDisplay){
    _clock.ClearAlarm1();
    if(updateDisplay)
        app.handle(globalState);
    preHibernateTasks();
    power::HibernateSystem();
}

void setup() {
    configurePins();
    power::LatchOnOffController();
    setCpuFrequencyMhz(80);

    esp_sleep_wakeup_cause_t wakeupCause = esp_sleep_get_wakeup_cause();
    bool wasHibernating = wakeupCause != ESP_SLEEP_WAKEUP_UNDEFINED;
    Wire.begin(pins::SDA, pins::SCL, 400000);

    // climate is priority because the MCU will heat up the board the longer it is on
    for (int i = 0; i < 5; i++)
    {
        // idk why, but sometimes it takes more than one try to get valid data from the SHT45
        if(globalState.lastClimateReading.humidity_raw != 0.0f)
            break;  
        getClimate(globalState.lastClimateReading); 
    }
    
    // display is near lower limit of operational temperature
    bool displayCold = globalState.lastClimateReading.Temperature_c() < Constants::lowTemperatureDisplayThreshold_C;

    Serial.begin();
    debugLogUSBConnected = power::USBConnected() && LoggerEnabled;

    // need this delay or the first messages are not recieved by my computer
    if(debugLogUSBConnected)
        delay(4000);
    
    if(wasHibernating)
        logl("Woke up from hibernation");
    else
        logl("Powered on");
    
    DateTime now;
    now = _clock.Read();
    
    // should be persistent, but it doesn't hurt to configure the alarm
    bool alarmWasSet = _clock.CheckAlarm();
    configureRTC();
    _clock.ClearAlarm1();
        
    PowerStatus ps;
    power::GetPowerStatus(ps);

    if (power::BatteryReconnected())
        power::ConfigureFuelGauge();

    globalState.currentTime = _clock.Read();

    app.eeprom = &eeprom;
    app.disp = &_display;
    app.clock = &_clock;
    app.globalState = &globalState;
    app.setState(State::StandardDisplay);

    // figure out what's going on
    {
        bool shouldFullResetDisplay = true;
        bool validState = eeprom.ValidateHeaderState();
        if(!validState){
            logl("header state invalid. Resetting..");
            eeprom.FactoryReset();
            eeprom.WriteSettings(DefaultSettings());
            app.setState(State::InvalidStateNotice);
        }
        
        auto res = eeprom.GetLastStatusHeader(globalState.currentHeader);

        // handle dead battery
        if(power::USBConnected() == false && (ps.batteryVoltage_mv <= Constants::lowBatteryThreshold_mv)){

            handleDeadBattery(displayCold, shouldFullResetDisplay);
            // unreachable code
        }
        globalState.currentHeader.displayingLowBattery = false;

        if(res == EEPROM::HeaderResult::ReadError){
            logl("failed to read EEPROM!");
            // ??? 
        }
        else{
            if(res == EEPROM::HeaderResult::NoHeadersFound){
                logl("EEPROM is empty. Starting new file");
                globalState.currentHeader = FreshHeader();
                power::ConfigureFuelGauge();
                eeprom.WriteSettings(DefaultSettings());
            }
            else {
                if(globalState.currentHeader.shutDownReason == ShutDownReason::Hibernate)
                {
                    logl("Last EEPROM header indicates hibernation");
                    globalState.currentHeader.shutDownReason = ShutDownReason::Unplanned;

                    // this was a healthy startup. Assume display is axxlready initialized
                    shouldFullResetDisplay = false;
                }
                else if(globalState.currentHeader.shutDownReason == ShutDownReason::PowerOff || globalState.currentHeader.shutDownReason == ShutDownReason::LowBattery)
                {
                    logl("Last EEPROM header indicates power cycle. Starting fresh header");
                    globalState.currentHeader = FreshHeader();
                    app.setState(State::WelcomeScreen);
                }
                else if(globalState.currentHeader.shutDownReason == ShutDownReason::FirmwareUpdate)
                {
                    logl("Last EEPROM header indicates firmware update.");
                    globalState.currentHeader.shutDownReason = ShutDownReason::FirmwareUpdate;

                    // updates cause multiple resets. After 4 full seconds of the CPU running without a reset, we can assume that the update has completed.
                    delay(4000);
                }
                else if(globalState.currentHeader.shutDownReason == ShutDownReason::Unplanned)
                {
                    logl("Last EEPROM header indicates unplanned shutdown");
                    app.setState(State::InvalidStateNotice);
                    globalState.currentHeader = FreshHeader();
                   eeprom.WriteSettings(DefaultSettings());
                }
                else{
                    MASSERT(false);
                    logf("unknown shutdown reason: %d", (int)globalState.currentHeader.shutDownReason);
                    eeprom.WriteSettings(DefaultSettings());
                }
            }

            logl("starting header");
            if(debugLogUSBConnected)
                delay(200);
            bool success = eeprom.StartNextStatusHeader(globalState.currentHeader);
            MASSERT(success);
            

            logl("updating header");
            if (debugLogUSBConnected)
               delay(200);
            success = eeprom.UpdateStatusHeader(globalState.currentHeader);
            MASSERT(success);
        }
        
        eeprom.ReadSettings(globalState.currentSettings);

        if(globalState.currentHeader.dataCount == 0 || alarmWasSet){
            eeprom.AddClimateSample(globalState.currentHeader, globalState.lastClimateReading);
        }

        bool displayingColdWarningScreen = false; // previus power cycle indicates the device screen has been too cold for some time already.
        if(displayCold){
            if(globalState.currentHeader.displayingCold == false){
                globalState.currentHeader.displayingCold = true;
                app.setState(State::LowTempWarning);
            }
            else{
                displayingColdWarningScreen = true; // can assume the display is already showing an underheat warning
            }
        }
        else {
            // reset the header flag once it warms back up
            if(globalState.currentHeader.displayingCold == true){
                globalState.currentHeader.displayingCold = false;
            }
        }

        _display.Init(shouldFullResetDisplay, &globalState.currentHeader);

        if(wasHibernating){
            if(alarmWasSet){
                logl("woke up due to alarm");
                
                if(power::USBConnected() == false){
                    // we woke up from our regular scheduled minute alarm. Do the normal routine and go back to sleep.
                    globalState.lastDeepWakeupCause = DeepWakeupCause::Alarm;
                    globalState.sleepIndicator = true;
                    
                    if(!displayingColdWarningScreen)
                        loadClimateDate();  

                    // if temperature dropped while night mode was active, clear the night mode flag
                    if(displayCold && globalState.currentHeader.displayingNightMode)
                        globalState.currentHeader.displayingNightMode = false;

                    // night screen: suppress display updates during configured night hours
                    if(!displayCold && globalState.currentSettings.nightScreen && isNightHours(globalState.currentTime)){
                        if(globalState.currentHeader.displayingNightMode){
                            // night screen already showing — skip display update, just record data and sleep
                            doAlarmRoutine(false);
                        } else {
                            // first entry into night mode — show night screen and persist the flag
                            app.setState(State::NightMode);
                            globalState.currentHeader.displayingNightMode = true;
                            doAlarmRoutine(true);
                        }
                        // unreachable: doAlarmRoutine calls HibernateSystem
                    }
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
void loop() {
    debugLogUSBConnected = power::USBConnected() && debugLogUSBConnected;

    bool btn1Filtered = debounceButton1(!getPinLevel(pins::menuBtn), millis(), false);
    updateButtonState(
        btn1Filtered,
        !getPinLevel(pins::powerBtn), // btn2 is already debounced by the LTC2954
        millis());
        
    // firmware updates cause multiple resets. Keep FirmwareUpdate reason until the
    // UpdateComplete screen is dismissed, which writes a clean reason to EEPROM.
    // The 10-second USB timeout below is a last-resort fallback.
    if(globalState.currentHeader.shutDownReason == ShutDownReason::FirmwareUpdate){
        if(power::USBConnected()){
            if(millis() - programStartTimer_ms > 10000){
                globalState.currentHeader.shutDownReason = ShutDownReason::Unplanned;
                eeprom.UpdateStatusHeader(globalState.currentHeader);
            }
        }
        // note: no else-branch here — if USB is disconnected the device will hibernate
        // via normal inactivity and preHibernateTasks() will handle the reason correctly.
    }

    if(firstLoop && getBtn2Down() == false && globalState.lastDeepWakeupCause == DeepWakeupCause::ButtonFromHibernate){
        // It's possible to wake up the device via button press and then release it quickly enough before it gets
        // registered by the button state manager. So if we just woke up and we know the button was just pressed according
        // to the wakeup source, we should still perform the button action (which is to enter the main menu)

        // if the device was showing the night screen, we actually want to show the standard diplay instead of skipping straight to the menu.
        if(manualWakeUpFromNightScreen == false)
            app.setState(State::MainMenu);
    }

    if(getBtn1() || getBtn2()){ 
        resetInactivity();
    }

    // poll the RTC once per second
    if(millis() - clockReadTimer_ms > 1000){
        clockReadTimer_ms = millis();
        globalState.currentTime = _clock.Read();
    }

    // handle manual shut down
    if (getBtn2HeldMS() >= 3000 && shuttingDown == false) {

        // Note:
        // The LTC2954 is configured to cut power after the button is held down for 6 seconds.
        // So we are effectivelly limited to 6 seconds to close up shop and shut down gracefully
        // before the LTC2954 activates its failsafe.

        globalState.currentHeader.shutDownReason = ShutDownReason::PowerOff;
        eeprom.UpdateStatusHeader(globalState.currentHeader);

        logl("shutting down...");

        shuttingDown = true;
        shutdownTimer = millis() - 3000;
        app.setState(State::ShutDownScreen);
    }

    if (shuttingDown && millis() - shutdownTimer >= 4000) {
        _display.FullClear();
        _display.ShutDown();

        if(power::USBConnected()){
            Serial.printf("powered down - %d\n", (int)(millis() - shutdownTimer));
            delay(100);
        }
        power::ShutdownSystem();

        // shouldn't ever get to this point unless powered by USB and a mistake was made. Shutting down isn't allowed while plugged in.
        while (shutdownTimer < 6500 && getPinLevel(pins::powerBtn) == true) {
            delay(1);
        }

        // That didn't work. I guess we'll just hibernate and pretend to be asleep? At least that way it will require a button press to turn back on
        shuttingDown = false;
        power::HibernateSystem();
    }

    // handle RTC alarm while already awake
    if (_clock.CheckAlarm()) {
        logl("alarm triggered");
        _clock.ClearAlarm1();

        for (int i = 0; i < 5; i++)
        {
            // idk why, but sometimes it takes more than one try to get valid data from the SHT45
            if(globalState.lastClimateReading.humidity_raw != 0.0f)
                break;  
            getClimate(globalState.lastClimateReading); 
        }

        eeprom.AddClimateSample(globalState.currentHeader, globalState.lastClimateReading);
 
        // there is a chance the battery has reached critical levels due to the user keeping the device away for a long time. Normally this 
        // is checked on device wake-up, but we should still check the battery at least once per minute when it is kept awake like this.

        if(power::USBConnected() == false){

            PowerStatus ps;
            power::GetPowerStatus(ps);

            if(ps.batteryVoltage_mv <= Constants::lowBatteryThreshold_mv){
                handleDeadBattery(false, false);
                // unreachable code
            }
        }

        if(app.getState() == State::StandardDisplay){
            app.setState(State::StandardDisplay); // refresh screen to reflect new time and temperature
        }
        else if(app.getState() == State::ChargingScreen){
            app.setState(State::ChargingScreen); // trigger periodic battery value check/update
        }
    }

    if(power::USBConnected()){
        pollUSB();

        if(power::ChargeStatus())
        {
            if(downloadingFirmware == false && LoggerEnabled == false){
                if(app.getState() != State::ChargingScreen && 
                app.getState() != State::InvalidStateNotice &&
                app.getState() != State::UpdateComplete){
                    app.setState(State::ChargingScreen);
                    globalState.currentHeader.displayingNightMode = false;
                }
            }
        }
    }
    else if(app.getState() == State::ChargingScreen)
    {
        // stop showing charging screen immedidately when unplugged
        resetInactivity();
        _display.EnableFullRefresh();
        app.setState(State::StandardDisplay);
    }


    // deep sleep due to inactivity
    if(
        !power::USBConnected() && !shuttingDown && 
        (millis() - deepSleepInactivityTimer_ms > GetDeepSleepInactivityThreshold_ms() || globalState.shouldGoToSleep))
    {
        _display.EnableFullRefresh();
        globalState.sleepIndicator = true;

        // bool displayColdNow = globalState.lastClimateReading.Temperature_c() < Constants::lowTemperatureDisplayThreshold_C;
        // if(!displayColdNow && globalState.currentSettings.nightScreen && isNightHours(globalState.currentTime)){
        //     // re-enter night mode when sleeping due to inactivity during night hours
        //     app.setState(State::NightMode);
        //     globalState.currentHeader.displayNightMode = true;
        // } else {
        //     globalState.currentHeader.displayNightMode = false;
        //     app.setState(State::StandardDisplay);
        // }

        app.setState(State::StandardDisplay);
        app.handle(globalState);
        preHibernateTasks();
        power::HibernateSystem();

        // unreachable code due to deep sleep
    }

    // light sleep due to inactivity
    if(!shuttingDown && millis() - lightSleepInactivityTimer_ms > GetLightSleepInactivityThreshold_ms()){
        _display.Hibernate();
        if(!power::USBConnected())
            doLightSleep();
    }

    app.handle(globalState);

    firstLoop = false;
}

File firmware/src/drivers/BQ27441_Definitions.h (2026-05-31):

/******************************************************************************
BQ27441_Definitions.h
BQ27441 LiPo Fuel Gauge Definitions
Jim Lindblom @ SparkFun Electronics
May 9, 2016
https://github.com/sparkfun/SparkFun_BQ27441_Arduino_Library

BQ27441 hardware constants, register addresses, and bit positions.

Hardware Resources:
- Arduino Development Board
- SparkFun Battery Babysitter

Development environment specifics:
Arduino 1.6.7
SparkFun Battery Babysitter v1.0
Arduino Uno (any 'duino should do)
******************************************************************************/

#pragma once

#define BQ72441_I2C_ADDRESS 0x55 // Default I2C address of the BQ27441-G1A

///////////////////////
// General Constants //
///////////////////////
#define BQ27441_UNSEAL_KEY	0x8000 // Secret code to unseal the BQ27441-G1A
#define BQ27441_DEVICE_ID	0x0421 // Default device ID

///////////////////////
// Standard Commands //
///////////////////////
// The fuel gauge uses a series of 2-byte standard commands to enable system 
// reading and writing of battery information. Each command has an associated
// sequential command-code pair.
#define BQ27441_COMMAND_CONTROL			0x00 // Control()
#define BQ27441_COMMAND_TEMP			0x02 // Temperature()
#define BQ27441_COMMAND_VOLTAGE			0x04 // Voltage()
#define BQ27441_COMMAND_FLAGS			0x06 // Flags()
#define BQ27441_COMMAND_NOM_CAPACITY	0x08 // NominalAvailableCapacity()
#define BQ27441_COMMAND_AVAIL_CAPACITY	0x0A // FullAvailableCapacity()
#define BQ27441_COMMAND_REM_CAPACITY	0x0C // RemainingCapacity()
#define BQ27441_COMMAND_FULL_CAPACITY	0x0E // FullChargeCapacity()
#define BQ27441_COMMAND_AVG_CURRENT		0x10 // AverageCurrent()
#define BQ27441_COMMAND_STDBY_CURRENT	0x12 // StandbyCurrent()
#define BQ27441_COMMAND_MAX_CURRENT		0x14 // MaxLoadCurrent()
#define BQ27441_COMMAND_AVG_POWER		0x18 // AveragePower()
#define BQ27441_COMMAND_SOC				0x1C // StateOfCharge()
#define BQ27441_COMMAND_INT_TEMP		0x1E // InternalTemperature()
#define BQ27441_COMMAND_SOH				0x20 // StateOfHealth()
#define BQ27441_COMMAND_REM_CAP_UNFL	0x28 // RemainingCapacityUnfiltered()
#define BQ27441_COMMAND_REM_CAP_FIL		0x2A // RemainingCapacityFiltered()
#define BQ27441_COMMAND_FULL_CAP_UNFL	0x2C // FullChargeCapacityUnfiltered()
#define BQ27441_COMMAND_FULL_CAP_FIL	0x2E // FullChargeCapacityFiltered()
#define BQ27441_COMMAND_SOC_UNFL		0x30 // StateOfChargeUnfiltered()

//////////////////////////
// Control Sub-commands //
//////////////////////////
// Issuing a Control() command requires a subsequent 2-byte subcommand. These
// additional bytes specify the particular control function desired. The 
// Control() command allows the system to control specific features of the fuel
// gauge during normal operation and additional features when the device is in 
// different access modes.
#define BQ27441_CONTROL_STATUS			0x00
#define BQ27441_CONTROL_DEVICE_TYPE		0x01
#define BQ27441_CONTROL_FW_VERSION		0x02
#define BQ27441_CONTROL_DM_CODE			0x04
#define BQ27441_CONTROL_PREV_MACWRITE	0x07
#define BQ27441_CONTROL_CHEM_ID			0x08
#define BQ27441_CONTROL_BAT_INSERT		0x0C
#define BQ27441_CONTROL_BAT_REMOVE		0x0D
#define BQ27441_CONTROL_SET_HIBERNATE	0x11
#define BQ27441_CONTROL_CLEAR_HIBERNATE	0x12
#define BQ27441_CONTROL_SET_CFGUPDATE	0x13
#define BQ27441_CONTROL_SHUTDOWN_ENABLE	0x1B
#define BQ27441_CONTROL_SHUTDOWN		0x1C
#define BQ27441_CONTROL_SEALED			0x20
#define BQ27441_CONTROL_PULSE_SOC_INT	0x23
#define BQ27441_CONTROL_RESET			0x41
#define BQ27441_CONTROL_SOFT_RESET		0x42
#define BQ27441_CONTROL_EXIT_CFGUPDATE	0x43
#define BQ27441_CONTROL_EXIT_RESIM		0x44

///////////////////////////////////////////
// Control Status Word - Bit Definitions //
///////////////////////////////////////////
// Bit positions for the 16-bit data of CONTROL_STATUS.
// CONTROL_STATUS instructs the fuel gauge to return status information to 
// Control() addresses 0x00 and 0x01. The read-only status word contains status
// bits that are set or cleared either automatically as conditions warrant or
// through using specified subcommands.
#define BQ27441_STATUS_SHUTDOWNEN	(1<<15)
#define BQ27441_STATUS_WDRESET		(1<<14)
#define BQ27441_STATUS_SS			(1<<13)
#define BQ27441_STATUS_CALMODE		(1<<12)
#define BQ27441_STATUS_CCA			(1<<11)
#define BQ27441_STATUS_BCA			(1<<10)
#define BQ27441_STATUS_QMAX_UP		(1<<9)
#define BQ27441_STATUS_RES_UP		(1<<8)
#define BQ27441_STATUS_INITCOMP		(1<<7)
#define BQ27441_STATUS_HIBERNATE	(1<<6)
#define BQ27441_STATUS_SLEEP		(1<<4)
#define BQ27441_STATUS_LDMD			(1<<3)
#define BQ27441_STATUS_RUP_DIS		(1<<2)
#define BQ27441_STATUS_VOK			(1<<1)
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

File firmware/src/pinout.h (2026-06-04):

#pragma once

namespace pins{
   constexpr int menuBtn = 2;
   constexpr int dsp_SDI = 6;
   constexpr int dsp_CLK = 7;
   constexpr int dsp_CS = 8;
   constexpr int dsp_DC = 9;
   constexpr int dsp_RST = 10;
   constexpr int dsp_BUSY = 11;
   constexpr int powerBtn = 14; 
   constexpr int USBDetect = 15; 
   constexpr int fuelGaugeGPIO = 17;
   constexpr int clockAlarm = 21; 
   constexpr int chargeStatus = 33;   
   constexpr int SCL = 34;   
   constexpr int SDA = 35;   
   constexpr int powerKill = 37;   
}

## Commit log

2026-05-31 initial public commit
    [BQ24075RGTR.step, DRY0006A.stp, ESP32-S3-MINI-1.STEP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]
2026-06-03 update PCB notes
2026-06-05 fix: removed implicit conversion by stting to int instead
    [app.h]
2026-06-08 remove schematic
2026-07-08 updated fuel guage configuration. Increased low battery threshold to 3.55V
2026-07-08 unify low battery threshold constants
2026-07-09 firmware update flow fixes
    [app.h, display.cpp, extra_script.py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]
2026-07-10 add battery charge percentage to charging screen
2026-07-10 working night mode, fix low battery detection, enable sleep on ViewData page
    [EEPROM.h, main.cpp, power.cpp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]
2026-07-14 folder structure, initial work on freecad case
    [assembly.scad, case_back.FCStd, case_back.scad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]
2026-07-14 progress on freecad models
    [assembly.FCStd, case_back.FCStd, case_front.FCStd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]
2026-07-15 snap fit
    [assembly.FCStd, case_back-Body.3mf, case_back.FCStd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]
2026-07-15 add thermometer icon, change screw holes from heat insert to self tap
    [assembly.FCStd, case_back.FCStd, case_front.FCStd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]
2026-07-16 export candidate 1
    [case_back-Body.3mf, case_back.3mf, case_back.FCStd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]
2026-07-16 add easter egg, fix slow wake up when plugging in, add more battery level checks
    [BQ27441.cpp, EEPROM.h, app.h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]
2026-07-21 Adafruit GFX protected function workaround. Fix spelling.
    [EEPROM.h, display.cpp]
2026-07-27 more assembly notes
2026-08-02 update readme for new battery life improvements
2026-10-29 Allow either button to dismiss invalid-state notice
